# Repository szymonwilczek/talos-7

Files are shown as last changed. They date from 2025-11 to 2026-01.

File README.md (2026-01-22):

# ⚡ Talos 7
### The Ultimate Open-Source SudoPad 

<div align="center">
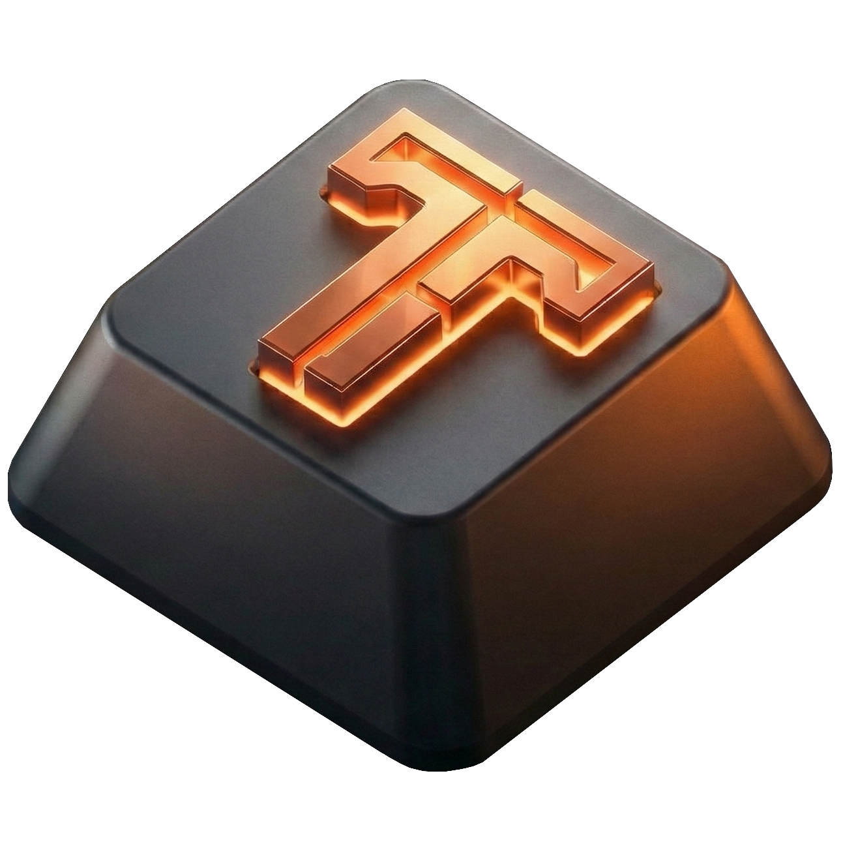
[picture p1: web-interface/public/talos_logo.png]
Talos 7 Logo
  
  <br/>
  
  
  
  
  

  <p>
    <b>Professional. Driverless. Infinite Possibilities.</b><br/>
    Designed for Streamers, Developers, and Creatives. <br/>
    Forged to automate.
  </p>
</div>

---

## 📸 Preview

<table>
  <tr>
    <td width="50%" align="center">
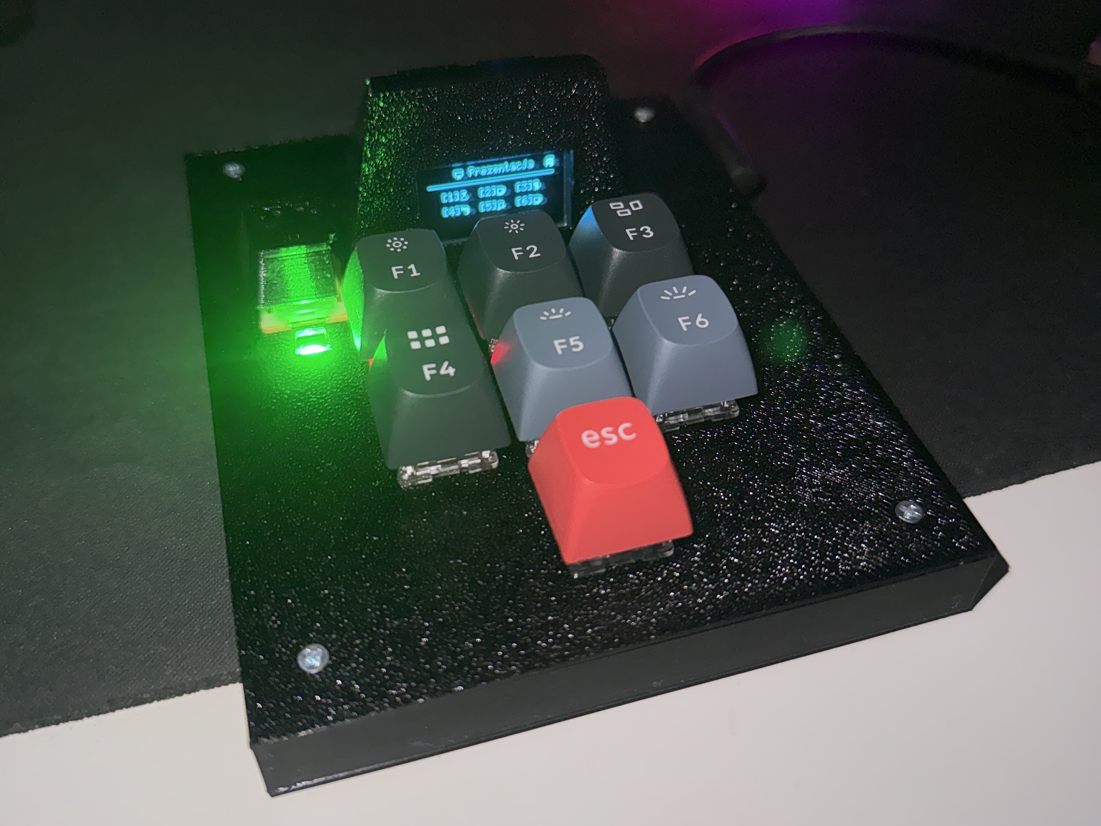
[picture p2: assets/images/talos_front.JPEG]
Talos Front
      
    </td>
    <td width="50%" align="center">
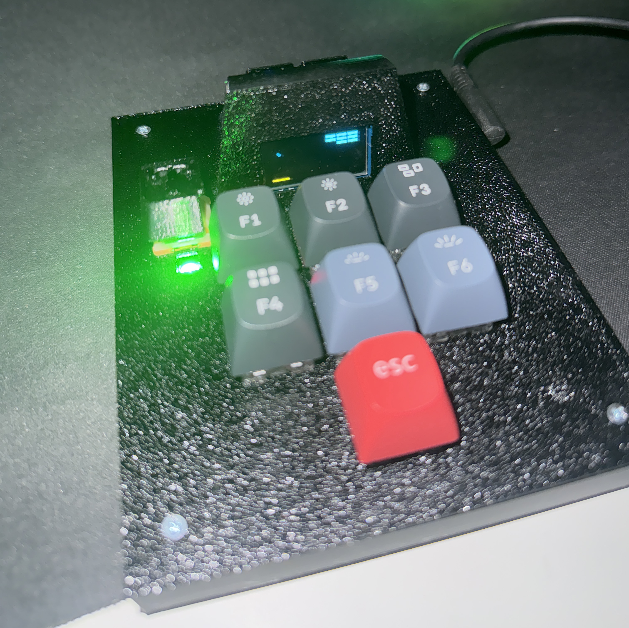
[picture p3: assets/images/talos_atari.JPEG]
Talos Back
      
    </td>
  </tr>
  <tr>
    <td colspan="2" align="center">
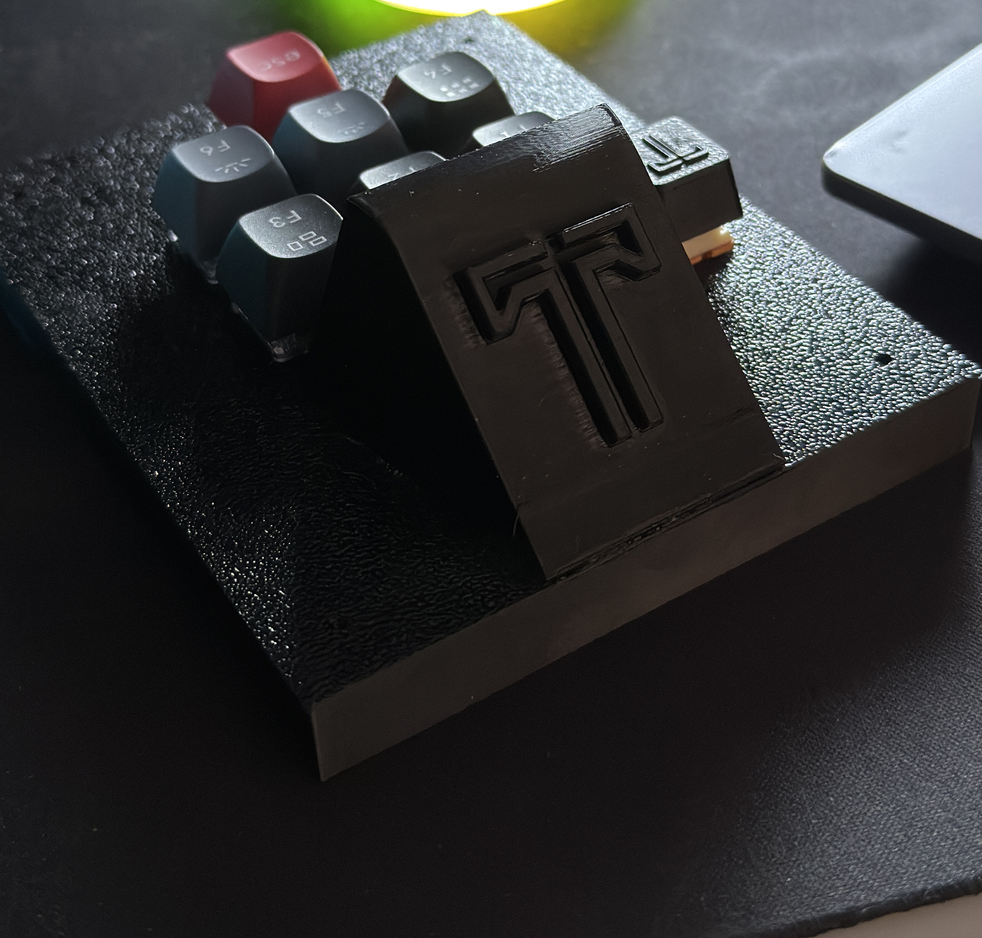
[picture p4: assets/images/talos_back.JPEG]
Atari Game
      
    </td>
  </tr>
</table>

<div align="center">
  <video src="https://github.com/user-attachments/assets/fb88e3e2-818f-48c2-9b6d-56c365594454" controls></video>
</div>

---

## 📖 Overview

**Talos 7** is not just a keypad; it's a hardware productivity platform. I've name this functionality as SudoPad. Unlike traditional macro pads that rely on heavy background software (like Synapse or iCUE), **Talos 7 runs everything on the device itself**.

Once configured via the web interface, you can plug it into **any computer** (Windows, macOS, Linux), and it will work instantly. No drivers. No background agents. Just pure hardware emulation.

### Why Talos?
* **Hybrid Device:** Simultaneously acts as a Keyboard, Mouse, MIDI Controller, and Serial Device.
* **OLED Dashboard:** A 128x64 pixel display gives you real-time feedback on layers and actions.
* **Web Configurator:** Modify your layout directly in Chrome/Edge using Web Serial API.
* **Hephaestus CI/CD:** Automated cloud builds ensure you always have the latest firmware.

---

## 🛠️ Hardware Architecture

Talos 7 is built on the accessible and powerful **Raspberry Pi Pico (RP2040)**.

### Bill of Materials (BOM)
* 1x **Raspberry Pi Pico**
* 7x **Mechanical Switches** (MX standard)
* 7x **Keycaps** (MX standard)
* 1x **SSD1306 OLED Display** (0.96", SPI Interface)
* 7x **LEDs** (0805, red)
* 10x **Resistors** (220R or 47R if you prefer dimmer light)
* 1x **RGB LED** (LTST-G563ZEGBW or FYLS-5050NRGBC)
* 1x **Micro-USB Data Cable**

### Wiring Diagram (Pinout)

See [Talos Schema](assets/board/talos_schema.pdf) for more information.

## 🚀 Setup & Installation

### 1. Flash the Firmware
You don't need to compile anything manually.
1.  Go to [**Releases**](https://github.com/szymonwilczek/talos-7/releases).
2.  Download the latest `talos7.uf2`.
3.  Hold the **BOOTSEL** button on your Pico while plugging it into USB.
4.  A drive named `RPI-RP2` will appear. Drag and drop the `.uf2` file there.
5.  The device will reboot. You should see the Talos Logo on the OLED.

### 2. Configure via Web
1.  Open the **[Talos Configurator](https://talos-7.vercel.app)** in a Chromium-based browser (Chrome, Edge, Opera).
2.  Click **Connect Device** and select *Talos 7*.
3.  **Customize** your layers and buttons.
4.  Click **Save Changes** to flash your config to the onboard memory.

---

## 🎛️ Macro Dictionary

Talos 7 supports **8 distinct action types** (for now, if you have something in mind, be welcome to propose). Here is a deep dive into each capabilities.

### 1. ⌨️ Key Press
Simulates a standard keyboard press.
* **Parameters:** Keycode (A-Z, F1-F12, etc.).
* **Use Case:** Muting Discord (`F13`), Screenshot (`PrintScreen`), Game abilities (`Q`, `W`, `E`).

### 2. ⛓️ Key Sequence
Executes a precise combination of up to 3 keys pressed simultaneously or sequentially.
* **Parameters:** List of keys + Modifiers (Ctrl, Alt, Shift, GUI).
* **Use Case:** `Ctrl` + `Shift` + `Esc` (Task Manager), `Win` + `Shift` + `S` (Snipping Tool).

### 3. 🔡 Text String
Types a text snippet automatically.
* **Parameters:** Text content (up to 32 chars).
* **Behavior:** Works like a super-fast typist. Supports basic Unicode.
* **Use Case:** Email signatures, Git commands (`git push origin main`), etc.

### 4. 🔄 Layer Toggle
Switches the active layer of the device.
* **Parameters:** Target Layer (Automatic Cycle).
* **Behavior:** Pressing this creates a loop: `Layer 1` → `Layer 2` → `Layer 3` → `Layer 4` → `Layer 1`.
* **Visuals:** The OLED instantly updates to show the new layer's name and icon.

### 5. 🖱️ Mouse Control
Takes hardware control of the mouse cursor.
* **Sub-types:**
    * **Move:** X/Y coordinates (relative). Great for AFK scripts.
    * **Click:** Left, Right, or Middle button (with Hold support).
    * **Wheel:** Scroll Up/Down.
* **Use Case:** "Cookie Clicker" macros, in-game AFK preventions, preventing screen lock.

### 6. 📜 Script Engine (Power User)
The most powerful feature. Talos acts as a "BadUSB" device to inject and execute complex scripts on the host machine.
* **Platform Awareness:** You can define separate scripts for Windows, Linux, and macOS on the same button.
* **Workflow:**
    1.  Talos opens a terminal using a shortcut (e.g., `Win+R` or `Ctrl+Alt+T` - those are just default, you can provide your own sequence if you have it).
    2.  It types a temporary script file to `/tmp` or `%TEMP%`.
    3.  It executes the file and deletes it immediately.
* **Use Case:** `docker-compose up -d`, SSH into a server, batch rename files, organize desktop.

### 7. 🎹 MIDI Note (Studio Mode)
Sends a MIDI Note On/Off signal via USB MIDI class.
* **Parameters:** Note (0-127), Velocity (0-127), Channel (1-16).
* **Why MIDI?** Unlike keyboard shortcuts, MIDI messages **never conflict** with typing and work even when the target app is in the background.
* **Integration:**
    * **OBS:** Use `obs-midi` plugin to switch scenes or toggle sources.
    * **DAWs:** Map to drum pads in FL Studio / Ableton.

### 8. 🎚️ MIDI Control Change (CC)
Sends a generic MIDI value (Potentiometer/Fader simulation).
* **Parameters:** CC Number (0-119), Value (0-127), Channel (1-16).
* **Use Case:**
    * **Lightroom:** Set Exposure to +1.0.
    * **Premiere Pro:** Set Timeline Zoom level.
    * **Windows Volume:** Use middleware (e.g., MidiKey2Key) to map CC to system volume.

### 9. 🕹️ Atari Breakout Game
A pleasant *Break* during work

---

## 🤖 DevOps: Hephaestus

This repository is managed by an automated github workflow named **Hephaestus**.

### Automated Versioning
I use **Semantic Versioning**. Hephaestus parses every commit message:
* `fix: ...` ➜ Bumps **Patch** (1.0.0 ➜ 1.0.1)
* `feat: ...` ➜ Bumps **Minor** (1.0.1 ➜ 1.1.0)
* `feat!: ...` ➜ Bumps **Major** (1.1.0 ➜ 2.0.0)

### Continuous Delivery
On every valid push to `main`:
1.  Hephaestus spins up a cloud environment with the **ARM GCC Toolchain**.
2.  It checks out the official **Pico SDK**.
3.  It compiles the firmware (`talos7.uf2`).
4.  It creates a **GitHub Release** with the new version and changelog.

---

## 🔧 Troubleshooting

### Device not connecting in browser?
* **Windows:** Ensure you are not blocking USB devices via Group Policy. No drivers needed.
* **Linux:** If you are unable to connect to the device via the web configurator on Linux (receiving `NetworkError: Failed to execute open on SerialPort`), you need to configure `udev` rules to allow non-root access to the Raspberry Pi Pico.

1. **Create a new udev rule file:**
   ```bash
   sudo nano /etc/udev/rules.d/99-talos.rules
   ```

2. **Add the following content**: This grants r/w permission to the device (Vendor ID 0x2e8a is RPi Pico):

```text
SUBSYSTEMS=="usb", ATTRS{idVendor}=="2e8a", MODE="0666"
KERNEL=="ttyACM*", ATTRS{idVendor}=="2e8a", MODE="0666"
```

3. Reload the rules and reconnect:

```bash
sudo udevadm control --reload-rules # reload
sudo udevadm trigger # apply changes
```

**Note for Fedora/RHEL users**: If connection issues persist, ModemManager might be interfering with the serial port. You can temporarily stop it with: `sudo systemctl stop ModemManager`

* **Browser:** Use Chrome, Edge, or Opera. Firefox/Safari do not support Web Serial yet.

### Firmware update failed?
If you "bricked" the configuration or the device is unresponsive:
1.  Unplug the device.
2.  Hold the physical **BOOTSEL** button on the Pico.
3.  Plug it in.
4.  Flash the `.uf2` again. This factory resets the core logic.

---

## 📄 License & Credits

* **Core Logic:** Szymon Wilczek
* **3D Case**: Kacper Kil, thanks a lot again!
* **Project Link:** [github.com/szymonwilczek/talos-7](https://github.com/szymonwilczek/talos-7)
* **License:** [MIT License](./LICENSE.md)

Thanks for interest in my project!

Built with ❤️ using **Raspberry Pi Pico SDK** and **TinyUSB**.

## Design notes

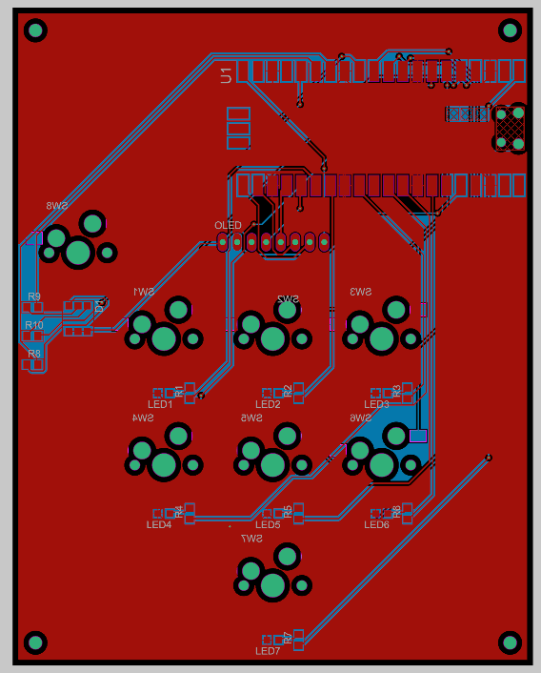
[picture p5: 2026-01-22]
assets/board/talos_board.png

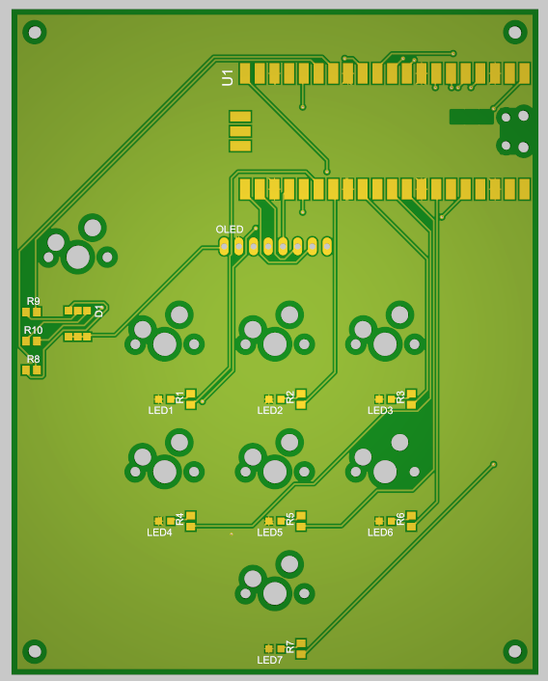
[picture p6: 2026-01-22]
assets/board/talos_board_3d_render.png

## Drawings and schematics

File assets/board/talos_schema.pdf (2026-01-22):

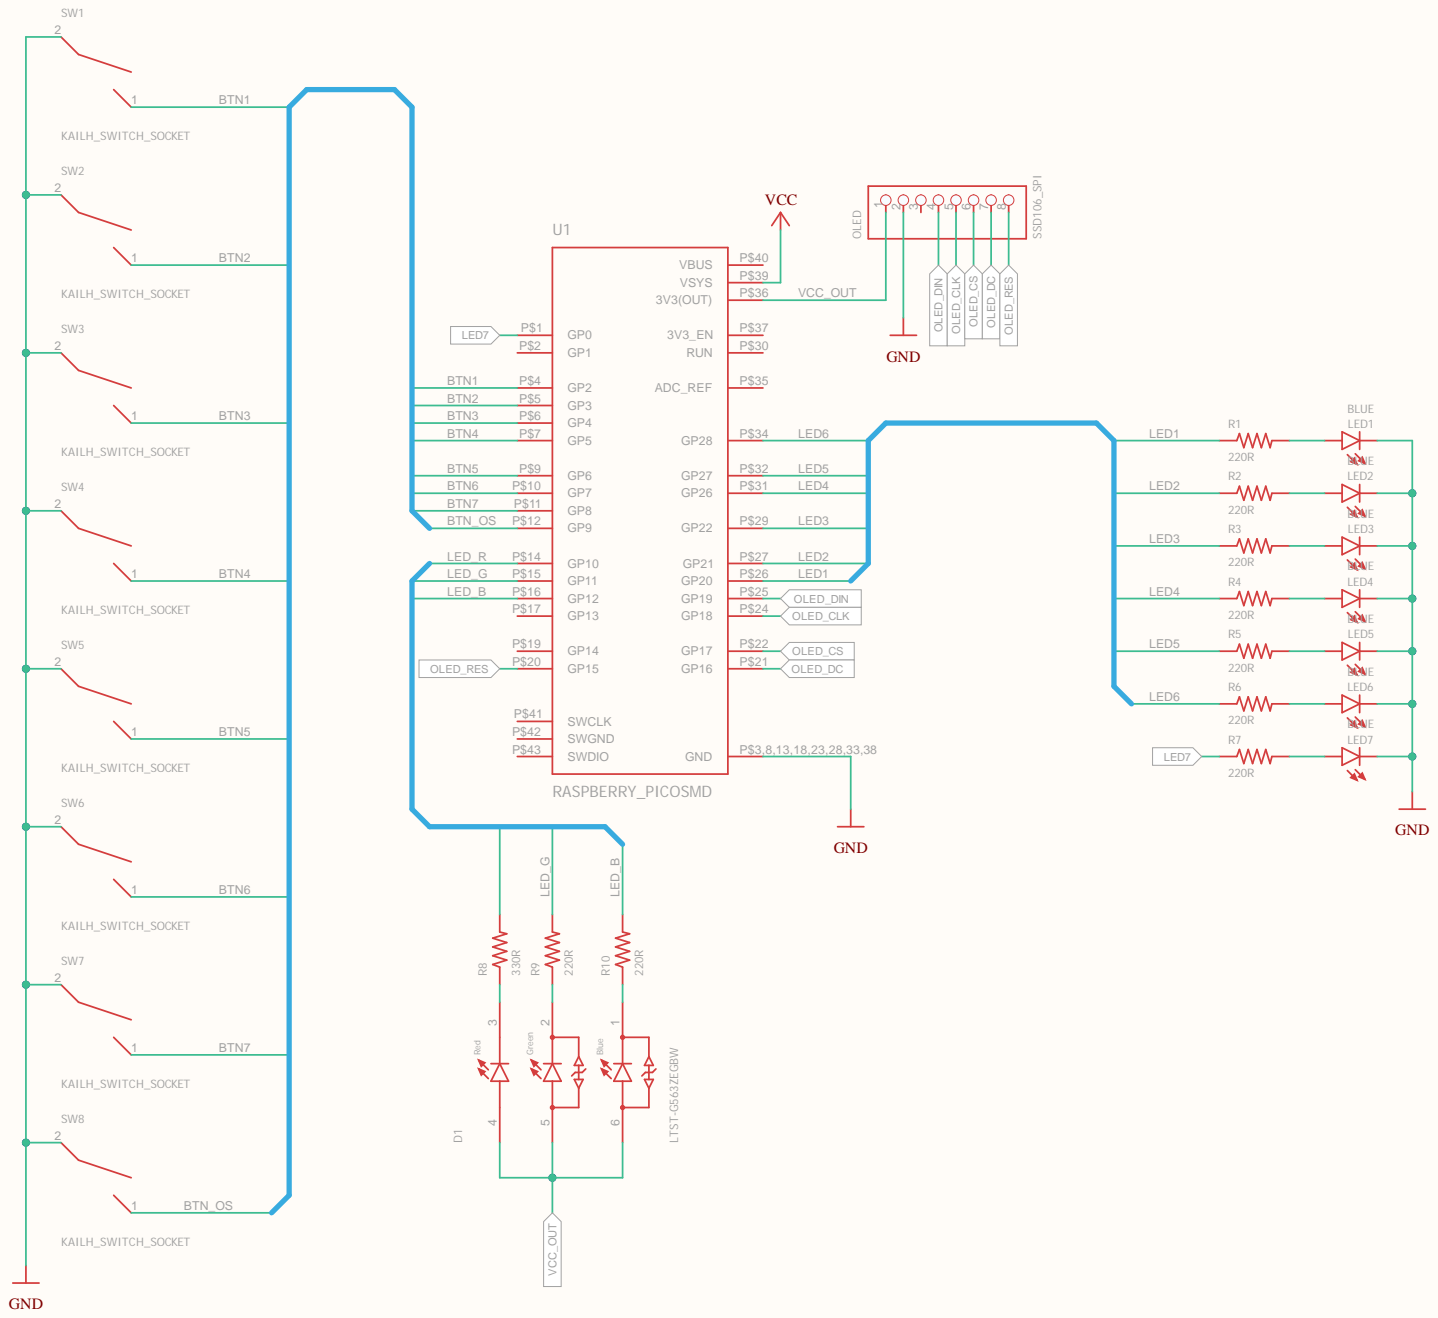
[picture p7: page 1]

BTN5 | 3 2 LED5
BTN6 | 3 1 LED4
BTN7 | 2 9 LED3

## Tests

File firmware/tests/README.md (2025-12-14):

# Talos 7 Firmware Unit Tests

Unit tests for Talos 7 firmware using the Unity Test Framework.

## Requirements 

- CMake 3.13+
- C compiler (gcc/clang)

## Running 

```bash
cd firmware/tests
mkdir build && cd build
cmake ..
make
./run_tests
```

## Structure 

```
tests/
├── unity/             # unity test framework
├── mocks/             # hardware mocks (pico, flash, tusb, gpio, watchdog)
├── test_*.c           # test files
├── test_runner.c      # main runner
└── CMakeLists.txt     # cmake config
```

## Tests 

| File | Testing | Tests |
|---|---|---|
| `test_macro_config.c` | CRC32, layer switching, factory defaults, structures | 17 |
| `test_hardware_interface.c` | HID keycodes mapping, GPIO mock | 10 |
| `test_exec_midi.c` | MIDI clamping, velocity/channel fallbacks | 13 |
| `test_cdc_cmd_write.c` | SET_MACRO parsing, validation | 9 |

**Total (currently): 49 tests**

## Adding new tests 

1. Create new file `test_xxx.c`
2. Add `void run_xxx_tests(void)` 
3. Add to `test_runner.c`
4. Add to `CMakeLists.txt`

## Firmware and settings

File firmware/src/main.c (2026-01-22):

#include "cdc/cdc_dispatcher.h"
#include "cdc/cdc_transport.h"
#include "easter_egg.h"
#include "executor/macro_executor.h"
#include "hardware/watchdog.h"
#include "hardware_interface.h"
#include "macro_config.h"
#include "oled/oled_display.h"
#include "pico/stdlib.h"
#include "pin_definitions.h"
#include "tusb.h"
#include <stdio.h>

volatile uint8_t g_detected_platform = 0;

uint8_t detect_platform(void) { return g_detected_platform; }

static bool button_processed[NUM_BUTTONS] = {false};
static bool prev_os_btn_state = true;
static uint32_t last_os_toggle_time = 0;

void check_os_toggle_button(void) {
  bool current_state = gpio_get(BTN_OS_TOGGLE_PIN);
  uint32_t now = to_ms_since_boot(get_absolute_time());

  if (prev_os_btn_state == true && current_state == false) {
    if (now - last_os_toggle_time > 200) {

      // platform: 0 -> 1 -> 2 -> 0 ...
      g_detected_platform++;
      if (g_detected_platform > 2) {
        g_detected_platform = 0;
      }

      switch (g_detected_platform) {
      case 0: // Linux
        cdc_log("[OS] Switched to LINUX (Manual)\n");
        break;

      case 1: // Windows
        cdc_log("[OS] Switched to WINDOWS (Manual)\n");
        break;

      case 2: // macOS
        cdc_log("[OS] Switched to MACOS (Manual)\n");
        break;
      }

      last_os_toggle_time = now;

      led_rgb_update_os(g_detected_platform);
      oled_wake_up();
      oled_display_layer_info(config_get_current_layer());
    }
  }
  prev_os_btn_state = current_state;
}

static void print_boot_message(void) {
  sleep_ms(4000); // czekanie na CDC connection

  cdc_log("\n");
  cdc_log("========================================\n");
  cdc_log("  MACRO KEYBOARD FIRMWARE \n");
  cdc_log("========================================\n");
  cdc_log("Device: Raspberry Pi Pico (RP2040)\n");
  cdc_log("USB VID:PID = 0x%04X:0x%04X\n", USB_VID, USB_PID);
  cdc_log("Buttons: %d (GP%d-GP%d)\n", NUM_BUTTONS, BTN_PIN_1, BTN_PIN_7);
  cdc_log("LEDs: %d (GP%d-GP%d)\n", NUM_BUTTONS, LED_PIN_1, LED_PIN_7);
  cdc_log("OLED: SPI0 (MOSI=GP%d, SCK=GP%d)\n", OLED_MOSI_PIN, OLED_SCK_PIN);
  cdc_log("Layers: %d\n", MAX_LAYERS);
  cdc_log("========================================\n");
  cdc_log("\n");
}

int main(void) {
  stdio_init_all();
  tusb_init();
  sleep_ms(1000);

  cdc_log("[BOOT] Waiting for CDC connection...\n");
  tud_task();
  if (tud_cdc_connected()) {
    cdc_log("[BOOT] CDC connected!\n");
  }
  sleep_ms(100);

  print_boot_message();

  cdc_log("[MAIN] Loading configuration...\n");
  config_init();

  cdc_log("[MAIN] Initializing CDC protocol...\n");
  cdc_protocol_init();

  cdc_log("[MAIN] Initializing hardware...\n");
  hardware_init();
  led_rgb_update_os(0); // default to Linux

  oled_display_layer_info(config_get_current_layer());
  leds_update_for_layer(config_get_current_layer());

  cdc_log("[MAIN] System ready!\n");
  cdc_log("[MAIN] Press Button 1 (GP%d) to test\n", BTN_PIN_1);
  cdc_log("\n");

  // button debounce
  uint32_t last_button_time[NUM_BUTTONS] = {0};
  const uint32_t DEBOUNCE_MS = 5;

  oled_wake_up();

  watchdog_enable(8000, 1);
  cdc_log("[MAIN] Watchdog enabled (8s timeout)\n");

  while (1) {
    watchdog_update();
    tud_task();
    cdc_protocol_task();

    // zarzadzanie wygaszaczem
    oled_power_save_task();

    oled_ui_task();

    check_os_toggle_button();

    uint32_t now = to_ms_since_boot(get_absolute_time());
    uint8_t current_layer = config_get_current_layer();

    for (int i = 0; i < NUM_BUTTONS; i++) {
      bool pressed = button_is_pressed(i);

      if (pressed && !button_processed[i] &&
          (now - last_button_time[i] > DEBOUNCE_MS)) {

        if (oled_is_active()) {
          // ekran aktywny -> wykonaj makro
          cdc_log("[MAIN] Button %d pressed! Executing macro.\n", i + 1);
          oled_wake_up(); // reset timera bezczynnosci
          execute_macro(current_layer, i);
        } else {
          // ekran wylaczony -> wybudz
          cdc_log("[MAIN] Button %d pressed! Waking up OLED.\n", i + 1);
          oled_wake_up();
          oled_display_layer_info(current_layer);
        }

        last_button_time[i] = now;
        button_processed[i] = true;
      } else if (!pressed) {
        button_processed[i] = false; // reset after release
      }
    }

    sleep_ms(1);
  }

  return 0;
}

// USB CDC Callbacks
void tud_cdc_rx_cb(uint8_t itf) { (void)itf; }

void tud_cdc_line_state_cb(uint8_t itf, bool dtr, bool rts) {
  (void)itf;
  (void)rts;

  if (dtr) {
    printf("[USB] CDC connected\n");
  } else {
    printf("[USB] CDC disconnected\n");
  }
}

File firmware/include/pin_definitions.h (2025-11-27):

#ifndef PIN_DEFINITIONS_H
#define PIN_DEFINITIONS_H

#include <stdint.h>

// ==================== GPIO PINS ====================
// przyciski
#define BTN_PIN_1 2
#define BTN_PIN_2 3
#define BTN_PIN_3 4
#define BTN_PIN_4 5
#define BTN_PIN_5 6
#define BTN_PIN_6 7
#define BTN_PIN_7 8
#define BTN_OS_TOGGLE_PIN 9

// LED
#define LED_PIN_1 20
#define LED_PIN_2 21
#define LED_PIN_3 22
#define LED_PIN_4 26
#define LED_PIN_5 27
#define LED_PIN_6 28
#define LED_PIN_7 0
#define PIN_RGB_R 10 // 330R
#define PIN_RGB_G 11 // 220R
#define PIN_RGB_B 12 // 220R

// OLED SPI
#define OLED_SPI spi0
#define OLED_MOSI_PIN 19 // GP19
#define OLED_SCK_PIN 18  // GP18
#define OLED_CS_PIN 17   // GP17
#define OLED_DC_PIN 16   // GP16
#define OLED_RST_PIN 15  // GP15

// ==================== USB CONFIGURATION ====================
// USB VID/PID - Raspberry Pi Foundation
#define USB_VID 0x2E8A
#define USB_PID 0x0032

// ==================== DEVICE CONSTANTS ====================
#define NUM_BUTTONS 7
#define MAX_LAYERS 4

// nazwy pinow
static const uint8_t BUTTON_PINS[NUM_BUTTONS] = {
    BTN_PIN_1, BTN_PIN_2, BTN_PIN_3, BTN_PIN_4,
    BTN_PIN_5, BTN_PIN_6, BTN_PIN_7};

static const uint8_t LED_PINS[NUM_BUTTONS] = {LED_PIN_1, LED_PIN_2, LED_PIN_3,
                                              LED_PIN_4, LED_PIN_5, LED_PIN_6,
                                              LED_PIN_7};

#endif // PIN_DEFINITIONS_H

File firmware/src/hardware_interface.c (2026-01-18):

#include "hardware_interface.h"

#include "cdc/cdc_transport.h"
#include "hardware/timer.h"
#include "macro_config.h"
#include "oled/oled_display.h"
#include "pico/stdlib.h"
#include "pin_definitions.h"
#include <stdio.h>
#include <string.h>

// button states
static volatile bool button_states[NUM_BUTTONS] = {false};
static bool button_prev_states[NUM_BUTTONS] = {false};

// LED states
static bool led_states[NUM_BUTTONS] = {false};

// Timer structure
static struct repeating_timer buttons_timer;

// BUTTON SCANNING CALLBACK (ISR)
static bool buttons_timer_callback(struct repeating_timer *t) {
  (void)t;

  for (int i = 0; i < NUM_BUTTONS; i++) {
    button_prev_states[i] = button_states[i];

    bool raw_state = !gpio_get(BUTTON_PINS[i]);

    button_states[i] = raw_state;
  }

  return true;
}

const char *get_key_name(uint8_t keycode) {
  static const char *key_names[] = {
      "A",     "B",   "C",         "D",   "E",     "F",   "G",   "H",   "I",
      "J",     "K",   "L",         "M",   "N",     "O",   "P",   "Q",   "R",
      "S",     "T",   "U",         "V",   "W",     "X",   "Y",   "Z",   "1",
      "2",     "3",   "4",         "5",   "6",     "7",   "8",   "9",   "0",
      "Enter", "Esc", "Backspace", "Tab", "Space", "F1",  "F2",  "F3",  "F4",
      "F5",    "F6",  "F7",        "F8",  "F9",    "F10", "F11", "F12", "→",
      "←",     "↓",   "↑"};
  if (keycode >= 4 && keycode <= 29)
    return key_names[keycode - 4]; // A-Z
  if (keycode >= 30 && keycode <= 39)
    return key_names[keycode - 30 + 26]; // 1-0
  if (keycode == 40)
    return "Enter";
  if (keycode == 41)
    return "Esc";
  if (keycode == 42)
    return "Backspace";
  if (keycode == 43)
    return "Tab";
  if (keycode == 44)
    return "Space";
  if (keycode >= 58 && keycode <= 69)
    return key_names[keycode - 58 + 36]; // F1-F12
  if (keycode >= 79 && keycode <= 82)
    return key_names[keycode - 79 + 48]; // arrows
  if (keycode == 224)
    return "Ctrl";
  if (keycode == 225)
    return "Shift";
  if (keycode == 226)
    return "Alt";
  if (keycode == 227)
    return "Meta";
  return "Key";
}

const char *format_sequence_short(key_step_t *sequence, uint8_t len) {
  static char buf[32];
  buf[0] = '\0';
  if (len == 0)
    return buf;

  // pierwszy klawisz + modyfikatory (vim like)
  char mods[8] = "";
  if (sequence[0].modifiers & 1)
    strcat(mods, "C"); // ctrl
  if (sequence[0].modifiers & 2)
    strcat(mods, "S"); // shift
  if (sequence[0].modifiers & 4)
    strcat(mods, "A"); // alt
  if (sequence[0].modifiers & 8)
    strcat(mods, "M"); // meta (gui)
  if (strlen(mods) > 0) {
    sprintf(buf, "<%s-%s>", mods, get_key_name(sequence[0].keycode));
  } else {
    strcpy(buf, get_key_name(sequence[0].keycode));
  }

  // nastepne klawisze
  for (int i = 1; i < len && i < 3; i++) {
    strcat(buf, "+");
    strcat(buf, get_key_name(sequence[i].keycode));
  }
  if (len > 3)
    strcat(buf, "...");
  return buf;
}

// ==================== BUTTONS ====================

void buttons_init(void) {
  for (int i = 0; i < NUM_BUTTONS; i++) {
    gpio_init(BUTTON_PINS[i]);
    gpio_set_dir(BUTTON_PINS[i], GPIO_IN);
    gpio_pull_up(BUTTON_PINS[i]); // pull-up (button connects to GND)
  }

  gpio_init(BTN_OS_TOGGLE_PIN);
  gpio_set_dir(BTN_OS_TOGGLE_PIN, GPIO_IN);
  gpio_pull_up(BTN_OS_TOGGLE_PIN);

  add_repeating_timer_ms(5, buttons_timer_callback, NULL, &buttons_timer);

  cdc_log("[BUTTONS] Initialized (%d buttons)\n", NUM_BUTTONS);
}

bool button_is_pressed(uint8_t button_index) {
  if (button_index >= NUM_BUTTONS)
    return false;
  return button_states[button_index];
}

// ==================== LED ====================

void leds_init(void) {
  for (int i = 0; i < NUM_BUTTONS; i++) {
    gpio_init(LED_PINS[i]);
    gpio_set_dir(LED_PINS[i], GPIO_OUT);
    gpio_put(LED_PINS[i], false);
  }
  cdc_log("[LEDS] Initialized (%d LEDs)\n", NUM_BUTTONS);
}

void led_set(uint8_t led_index, bool state) {
  if (led_index >= NUM_BUTTONS)
    return;
  led_states[led_index] = state;
  gpio_put(LED_PINS[led_index], state);
}

void led_toggle(uint8_t led_index) {
  led_set(led_index, !led_states[led_index]);
}

void leds_update_for_layer(uint8_t layer) {
  // turn off all LEDs, then turn on LED for current layer (if layer < 7)
  for (int i = 0; i < NUM_BUTTONS; i++) {
    led_set(i, false);
  }

  if (layer < NUM_BUTTONS - 1) {
    led_set(layer, true);
  }
}

void led_rgb_init(void) {
  gpio_init(PIN_RGB_R);
  gpio_set_dir(PIN_RGB_R, GPIO_OUT);

  gpio_init(PIN_RGB_G);
  gpio_set_dir(PIN_RGB_G, GPIO_OUT);

  gpio_init(PIN_RGB_B);
  gpio_set_dir(PIN_RGB_B, GPIO_OUT);

  // common anode: 1 = OFF
  gpio_put(PIN_RGB_R, 1);
  gpio_put(PIN_RGB_G, 1);
  gpio_put(PIN_RGB_B, 1);

  cdc_log("[RGB] Initialized (Common Anode) on pins %d, %d, %d\n", PIN_RGB_R,
          PIN_RGB_G, PIN_RGB_B);
}

void led_rgb_set(bool r, bool g, bool b) {
  gpio_put(PIN_RGB_R, !r);
  gpio_put(PIN_RGB_G, !g);
  gpio_put(PIN_RGB_B, !b);
}

void led_rgb_update_os(uint8_t platform) {
  switch (platform) {
  case 0: // Linux -> GREEN (G only)
    led_rgb_set(0, 1, 0);
    break;
  case 1: // Windows -> BLUE (B only)
    led_rgb_set(0, 0, 1);
    break;
  case 2: // macOS -> CYAN (G + B)
    led_rgb_set(0, 1, 1);
    break;
  default: // off or error -> BLUE (red is broken)
    led_rgb_set(0, 0, 1);
    break;
  }
}
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

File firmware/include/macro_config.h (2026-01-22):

#ifndef MACRO_CONFIG_H
#define MACRO_CONFIG_H

#include <stdbool.h>
#include <stdint.h>

// ==================== CONFIGURATION CONSTANTS ====================
#define MAX_LAYERS 4
#define NUM_BUTTONS 7
#define MACRO_STRING_LEN 32
#define MAX_NAME_LEN 16
#define MAX_EMOJI_LEN 8
#define MAX_SCRIPT_SIZE 2048
#define FLASH_SECTOR_SIZE_CALC                                                 \
  ((sizeof(config_data_t) + 4095) & ~4095) // zaokraglenie do wieloktronosci 4KB

// ==================== SEKWENCJE KLAWISZY ====================
typedef struct {
  uint8_t keycode;   // HID keycode
  uint8_t modifiers; // modyfikatory (bitmask)
  uint16_t duration; // czas trzymania (ms) lub ilosc powtorzen
} key_step_t;

#define MAX_SEQUENCE_STEPS 5
#define MODIFIER_LEFT_CTRL (1 << 0)   // 0x01
#define MODIFIER_LEFT_SHIFT (1 << 1)  // 0x02
#define MODIFIER_LEFT_ALT (1 << 2)    // 0x04
#define MODIFIER_LEFT_GUI (1 << 3)    // 0x08 (Windows/Super/Cmd)
#define MODIFIER_RIGHT_CTRL (1 << 4)  // 0x10
#define MODIFIER_RIGHT_SHIFT (1 << 5) // 0x20
#define MODIFIER_RIGHT_ALT (1 << 6)   // 0x40
#define MODIFIER_RIGHT_GUI (1 << 7)   // 0x80

// ==================== TYPY MAKR ====================
typedef enum {
  MACRO_TYPE_KEY_PRESS = 0,    // pojedynczy klawisz (HID keycode)
  MACRO_TYPE_TEXT_STRING = 1,  // tekst do wpisania
  MACRO_TYPE_LAYER_TOGGLE = 2, // przelaczanie warstw
  MACRO_TYPE_SCRIPT = 3,       // skrypt do wykonania
  MACRO_TYPE_KEY_SEQUENCE = 4, // sekwencja klawiszy
  MACRO_TYPE_MOUSE_BUTTON = 5, // klikniecie (LPM, PPM, Middle)
  MACRO_TYPE_MOUSE_MOVE = 6,   // ruch (X, Y)
  MACRO_TYPE_MOUSE_WHEEL = 7,  // scroll
  MACRO_TYPE_MIDI_NOTE = 8,    // odtworzenie nuty MIDI
  MACRO_TYPE_MIDI_CC = 9,      // wyslanie komunikatu MIDI CC
  MACRO_TYPE_GAME = 10         // Atari Breakout Game
} macro_type_t;

// ==================== STRUKTURA MAKRA ====================
typedef struct {
  macro_type_t type;
  uint16_t value;        // keycode lub target layer
  int16_t move_x;        // ruch myszy X
  int16_t move_y;        // ruch myszy move_y
  uint16_t repeat_count; // ilosc powtorzen
  uint16_t repeat_interval;
  char macro_string[MACRO_STRING_LEN];              // tekst makra
  char name[MAX_NAME_LEN];                          // nazwa makra
  uint8_t emoji_index;                              // indeks emoji
  char script[MAX_SCRIPT_SIZE];                     // skrypt makra
  uint8_t script_platform;                          // platforma skryptu
  key_step_t terminal_shortcut[MAX_SEQUENCE_STEPS]; // skrot terminala
  uint8_t terminal_shortcut_length;                 // dlugosc skrotu
  key_step_t sequence[MAX_SEQUENCE_STEPS];          // sekwencja klawiszy
  uint8_t sequence_length;                          // dlugosc sekwencji
} macro_entry_t;

// ==================== GLOBALNA KONFIGURACJA ====================
typedef struct {
  char layer_names[MAX_LAYERS][MAX_NAME_LEN];    // nazwy warstw
  uint8_t layer_emojis[MAX_LAYERS];              // emoji warstw
  macro_entry_t macros[MAX_LAYERS][NUM_BUTTONS]; // wszystkie makra
  uint32_t crc32;                                // checksum
  uint8_t global_text_platform;                  // domyslna platforma tekstu
  uint32_t oled_timeout_s;                       // timeout wygaszacza OLED
} config_data_t;

// ==================== FLASH STORAGE ====================
#define FLASH_TARGET_OFFSET (1024 * 1024) // 1MB offset
#define FLASH_SECTOR_SIZE 4096            // 4KB sector

// ==================== FUNKCJE PUBLICZNE ====================

void config_init(void);
config_data_t *config_get(void);
bool config_save(void);
void config_set_factory_defaults(void);
uint32_t config_calculate_crc(const config_data_t *config);
uint8_t config_get_current_layer(void);
void config_cycle_layer(void);
uint8_t detect_platform(void);

#endif // MACRO_CONFIG_H

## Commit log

2025-11-15 feat: defined macro config for pi pico
2025-11-15 feat: defined pin definitions for pi pico
2025-11-15 feat: imported pico sdk import cmake library
2025-11-15 feat: main file for firmware configuration for pi pico
2025-11-15 feat: ingoring pico-sdk in git commits
2025-11-15 feat: main serial service for whole pico operations handling
2025-11-15 feat: removed unused macro slot component
2025-11-15 feat: better visualisation of project board layout on web interface
2025-11-15 feat: realistic buttons on web-interface
2025-11-18 feat: implemented key sequences in button edit
2025-11-18 feat: improved oled display for showing actual button macro
2025-11-18 feat: included hardware spi configuration for oled display
2025-11-18 fix: pins definitions
    this needed to be changed to proper ones
    [pin_definitions.h]
2025-11-18 fix: oled display layout in hardware interface
    [hardware_interface.c]
2025-11-19 feat: centering buttons in firmware for oled
2025-11-19 feat: displaying button name on oled during click
    also centered whole layout
2025-11-19 feat: new limiters for sequence and button name
2025-11-19 feat: dynamic platform (os) detecting
    for windows using OS Fingerprint, for macOS holding button 1, for Linux: default
2025-11-20 fix: displaying sequences on oled display (firmware)
    [hardware_interface.c]
2025-11-21 feat: unique id for pico when plugged in
2025-11-21 feat: preventing oled burnout by settings afk timeout
    [hardware_interface.c, macro_config.h, main.c]
2025-11-21 feat: implementing interrupting spam clicking
2025-11-21 feat: centering layer & button name for oled display (WI)
2025-11-21 fix: proper assembling terminal shortcut for scripts
    closes #8
2025-11-21 fix: missing imports of oled_display
    [main.c]
2025-11-22 fix: imports of new cdc logic
    [hardware_interface.c, main.c, oled_display.c]
2025-11-22 fix: missingimport for macro executor(s)
    [main.c]
2025-11-23 fix: oled display (F/WI) info about new MIDI Notes/CC
    [oled_display.c]
2025-11-24 feat: interrupts configuration for matrix rain
2025-11-24 feat!: buttons made on interrupts, not sync waiting
2025-11-24 feat: async oled layer trigger (for interrupts on buttons)
2025-11-24 feat: divided button edit dialog into separate components
2025-11-24 fix: deleted old pcb visualization component
2025-11-25 fix: changed usb_pid specifically for windows os
    [pin_definitions.h]
2025-11-25 reverted to original descriptors configuration
    i fucked something up, even linux wasn't working.
    [pin_definitions.h]
2025-11-25 fix: filters in serial.transport.ts
    This ensures, that the device is properly recognized as I've updated the firmware USB_PID.
2025-11-25 feat!: complete firmware for windows & linux descriptors
    I finally figured it out! There was a missing IAD for MIDI
    [pin_definitions.h]
2025-11-26 Revise BOM with additional details and clarifications
    Updated Bill of Materials with personal notes on components.
2025-11-26 Fix LED resistor notation in README
2025-11-26 feat: windows script execution in powershell file
    Previously, it wasn't creating powershell files.
2025-11-27 fix: removed usbProductId from port filters
2025-11-27 feat: possibility of changing platform via external button
    Closes #6 and closes #9
2025-11-27 feat: rgb led os indicator
2025-11-28 feat: hardware watchdog for system stability
    - Enable hardware watchdog timer with 2000ms timeout in main.c
    - Add periodic watchdog feeding (kicking) to the main execution loop
    - Link hardware_watchdog library in CMakeLists.txt
    This ensures the device automatically resets in case of an EMI event
    or infinite loop hang, improving commercial robustness.
    [main.c]
2025-12-01 fix: matrix rain oled screen saver
    [main.c, oled_display.c]
2025-12-14 fix: prevent buffer overflow in text preview
    The size of the safe_preview buffer has been increased from 16 to 20 bytes, and the
    unsafe strcat() function has been replaced with strncat() with an explicit size limit.
    This prevents a potential buffer overflow when displaying a preview of the macro text
    on the OLED screen when the text contains Unicode characters converted to ‘?’.
    Changed files:
    - firmware/src/oled/oled_display.c
    [oled_display.c]
2025-12-14 fix: add input validation to cdc_receive_sequence
    Added validation of input parameters in the cdc_receive_sequence() function:
    - Checking whether layer and button are within the allowed limits (< MAX_LAYERS, < NUM_BUTTONS)
    - Checking whether the steps pointer is not NULL
    - Limiting count to MAX_SEQUENCE_STEPS before use
    This prevents potential out-of-bounds reads, memory corruption, and undefined
    behavior when receiving invalid data from the web interface.
    - firmware/src/cdc/cdc_dispatcher.c
    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
2025-12-14 fix: apply MIDI fallback values consistent with firmware
    Added fallback values when parsing MIDI macros in the web interface, consistent with the logic
    in the firmware:
    - MIDI velocity: default 127 when value <= 0
    - MIDI channel: default 1 when value <= 0
    - MIDI CC value: default 127 when value < 0 (0 is acceptable for CC)
    This ensures consistency between the values displayed in the UI and the actual
    behavior of the firmware when playing MIDI.
    - web-interface/lib/services/serial.service.ts
    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
2025-12-14 fix: add error handling to serial disconnect
    Robust error handling has been added to the disconnect() function:
    - Each operation (reader, writer, port) is now wrapped in a try-catch block
    - Incorrect await on the synchronous releaseLock() method has been removed
    - .catch(() => {}) has been added to reader.cancel() to catch errors before releaseLock
    This prevents the application from crashing when:
    - The device was physically disconnected before calling disconnect
    - The port is already closed
    - The stream is already canceled
    - web-interface/lib/services/serial.transport.ts
    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
2025-12-14 fix: remove unnecessary flash write on boot
    Removed unnecessary call to config_save() after successfully loading configuration
    from flash in config_init() function.
    Flash has a limited number of write cycles (~100,000). Previously, each device startup
    used one write cycle unnecessarily, which could lead to premature flash memory degradation.
    Now, writing to flash only occurs when:
    - The configuration is empty/corrupted and factory defaults are loaded
    - The user explicitly saves changes via the web interface (SAVE_FLASH)
    - firmware/src/macro_config.c
    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
2025-12-14 fix: remove duplicate boot log messages
    Duplicate logs in the print_boot_message() function have been removed.
    Previously, information about buttons, LEDs, OLEDs, and layers was printed twice each time the device was started, which cluttered
    the serial console output.
    - firmware/src/main.c
    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
    [main.c]
2025-12-14 fix: increase response format buffer size
    The buffer size in cdc_send_response_fmt() has been increased from 256 to 512 bytes.
    The previous size could be insufficient when sending configurations containing long macro names, text strings, or other data, which led
    to truncated responses and potential data loss when reading the configuration.
    - firmware/src/cdc/cdc_transport.c
    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
2025-12-14 fix: add NaN validation for parseInt in config parsing
    Added validation of values returned by parseInt() in parsing functions configuration:
    parseLayerName():
    - Check that layerIdx is not NaN and is within range
    - Fallback to 0 for invalid emojiIdx
    parseMacroLine():
    - Check that layer, button, and type are not NaN
    - Range validation for layer and button before accessing the array
    This prevents undefined behavior when receiving corrupted or invalid data from the firmware.
    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
2025-12-14 fix: add buffer size limit to prevent memory leak in readLine
    A buffer size limit (64KB) has been added to the readLine() function.
    If data arrives without a newline character, the buffer could grow indefinitely, leading to a memory leak. Now, when the buffer exceeds MAX_BUFFER_SIZE:
    - The buffer is cleared
    - An error is thrown: “Buffer overflow - no newline received”
    This prevents memory problems with incorrect data streams from the device.
    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
2025-12-14 fix: replace silent return with continue in handleSaveChanges
    Quiet return has been replaced with continue with logging in the handleSaveChanges() function.
    Previously, when the macro was undefined, the entire save function was interrupted without any feedback to the user. Now:
    - A warning is logged in the console with information about which button has a problem
    - The loop continues processing the remaining changes
    - The duplicate !macro check in the else block has been removed
    This ensures that a single incorrect change does not block the saving of the remaining correct changes.
    - web-interface/components/editor/configurator.tsx
    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
2025-12-14 fix: remove duplicate function declaration
    Removed duplicate declaration of the config_get_current_layer() function in the macro_config.h header file.
    The function was declared twice (lines 88 and 90). The C compiler accepts repeated declarations, but this is unnecessary and clutters the code.
    - firmware/include/macro_config.h
    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
    [macro_config.h]
2025-12-14 fix: fix unused macro_count variable in GET_CONF
    Fixed incorrect “Sent 0 macros” log in cmd_handle_get_conf() function.
    Problem: macro_count variable was declared but never incremented, so the log always showed 0 even though macros were sent.
    Solution: the unused variable was removed and replaced with the expression MAX_LAYERS * NUM_BUTTONS, which accurately reflects the number of macros sent (4 layers × 7 buttons = 28).
    - firmware/src/cdc/commands/cdc_cmd_read.c
    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
2025-12-14 fix: add layer index validation in display function
    Added validation of the layer parameter at the beginning of the oled_display_layer_info() function.
    If layer >= MAX_LAYERS:
    - The message “Invalid layer!” is displayed on the OLED
    - The function returns without attempting to access the array
    This prevents out-of-bounds access with an invalid layer index, which could lead to undefined behavior or device crash.
    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
    [oled_display.c]
2025-12-14 feat: increase timeout and feed during flash operations
    The watchdog timeout has been increased from 2s to 8s and feeding has been added during flash writing.
    Changes in main.c:
    - watchdog_enable(8000, 1) instead of watchdog_enable(2000, 1)
    Changes in macro_config.c:
    - #include “hardware/watchdog.h” added
    - watchdog_update() before buffer preparation
    - watchdog_update() before flash operation (last chance before interrupts are disabled)
    - watchdog_update() immediately after flash operation
    - watchdog_update() after CRC verification
    - Sleep after flash shortened from 100ms to 50ms
    - printf logs uncommented for better debugging
    - Added detailed CRC error information
    This solves the prob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
    [main.c]
2025-12-14 feat: add retry mechanism to serial communication
    An automatic retry mechanism has been added to the sendCommandCheckOK() function.
    Configuration:
    - maxRetries: 3 attempts
    - retryDelayMs: 500ms delay between attempts
    Functionality:
    - In case of failure (timeout, incorrect response), automatically retries
    - Logs each failed attempt to the console with the attempt number
    - After exhausting attempts, throws an error with the last message
    - Works for all commands using sendCommandCheckOK:
    - setMacro, setLayerName, setOledTimeout, saveFlash, setConfigMode, etc.
    This increases the reliability of communication with the device, especially with an unstable USB connection or overloaded firmware.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
2025-12-14 chore(ci): exclude tests folder from release triggers
    Added exclusion ‘firmware/tests/**’ from path triggers in the Hephaestus workflow.
    Now changes in the unit test folder will not trigger:
    - A new firmware build
    - A version bump
    - The creation of a new release
    Regarding .uf2: tests are NO longer compiled into firmware because:
    - The tests/ folder has a separate CMakeLists.txt
    - The main CMakeLists.txt does not include test files
    - Tests compile as a native executable (run_tests), not as ARM firmware
    - .github/workflows/bump-firmware.yml
    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
2025-12-14 feat: unity framework for unit tests
2026-01-18 fix: updated OS colors
    By accident I've destroyed one of the diode pads during soldering (the red one).
    I needed to come up with a truly engineered solution - instead of using the red color, I'm using single colors and their combination. I'm satisfied by now in that solution.
    [hardware_interface.c]
2026-01-22 feat(web): support Atari Breakout game macro
    Added MACRO_TYPE_GAME (10) to config.types.ts.
    Updated ButtonEditDialog to allow selecting Atari Breakout from the Macro Type dropdown.
    Updated OLEDDisplay to visualize the game macro as 'Atari Breakout' instead of Unknown Action.
2026-01-22 docs: add project preview media to README
    Added a Preview section to the top of README.md showcasing the device and the Atari Breakout easter egg.
    Included media files in assets/:
    - talos_front.JPEG
    - talos_back.JPEG
    - talos_atari.JPEG
    - atari_preview.MP4
2026-01-22 docs: update README and add board assets
    README updates, more assets - including board ones (3D render, PDF
    schematic)
    [talos.brd]
2026-02-15 feat: turn off diodes when device is inactive
    Previous implementation assumed, that the device will always be
    connected to the electricity - well, that's partially right, since it IS
    indeed always connected. BUT: the RGB diode is really, really BRIGHT.
    The resistors are probably messed up. Nevertheless, the RGB diode and
    the buttons status diodes are now automatically turning on/off when OLED
    is going to sleep and wake up.
2026-07-17 fix(firmware): add missing pico/stdlib.h include in cdc_cmd_write
    sleep_ms() relied on an implicit declaration; GCC 14 promotes
    implicit declarations to errors, breaking local builds.
2026-07-17 feat: add per-key LED modes and LED master toggle
    Button LEDs died with the OLED, all or nothing.
    Each key can be set to Reactive (follows the display) or Always On
    from the new Per-Key Lighting section in the web dashboard.
    New LED Toggle macro type (11) acts as a runtime master switch:
    one press kills every LED, a second press restores them,
    Always On mappings included - no need to unmap anything for the night.
    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
2026-07-17 fix: add LED Toggle action label to OLED preview
    LED Toggle buttons rendered as "Unknown Action" on both the device
    OLED and the dashboard OLED mock. Firmware shows the transition based
    on the live master switch state (ON -> OFF / OFF -> ON); the preview
    draws before the toggle executes, so the direction is accurate.
2026-07-17 feat!: remove layer indicator from button LEDs
    Button LEDs no longer mirror the active layer (LED N lit while layer
    N is active).
    LEDs are driven purely by per-key lighting modes and the master toggle:
    Always On keys stay lit, Reactive keys only flash on press.
    leds_update_for_layer()/leds_sleep() collapse into a single leds_refresh().
    BREAKING CHANGE: the active layer is no longer indicated on the
    button LEDs; the OLED layer info is the only layer indicator.
